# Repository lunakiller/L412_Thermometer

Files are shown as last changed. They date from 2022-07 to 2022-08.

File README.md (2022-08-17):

# L412 Thermometer
Temperature and humidity station powered by STM32L412KB MCU. The goal of the project is the longest possible battery life.

## Main components
- STM32L412KBT6 MCU
- Si7021 temperature and humidity sensor
- LCD display with PCD8544 driver
- 600mAh Li-Ion battery

## Goals
- [x] Build it on the breadboard
- [x] Show temperature and humidity data on the display
- [x] Run from the battery
- [x] Design PCB
- [ ] Measure battery voltage
- [ ] Sync time through USB
- [ ] Design 3D printed case

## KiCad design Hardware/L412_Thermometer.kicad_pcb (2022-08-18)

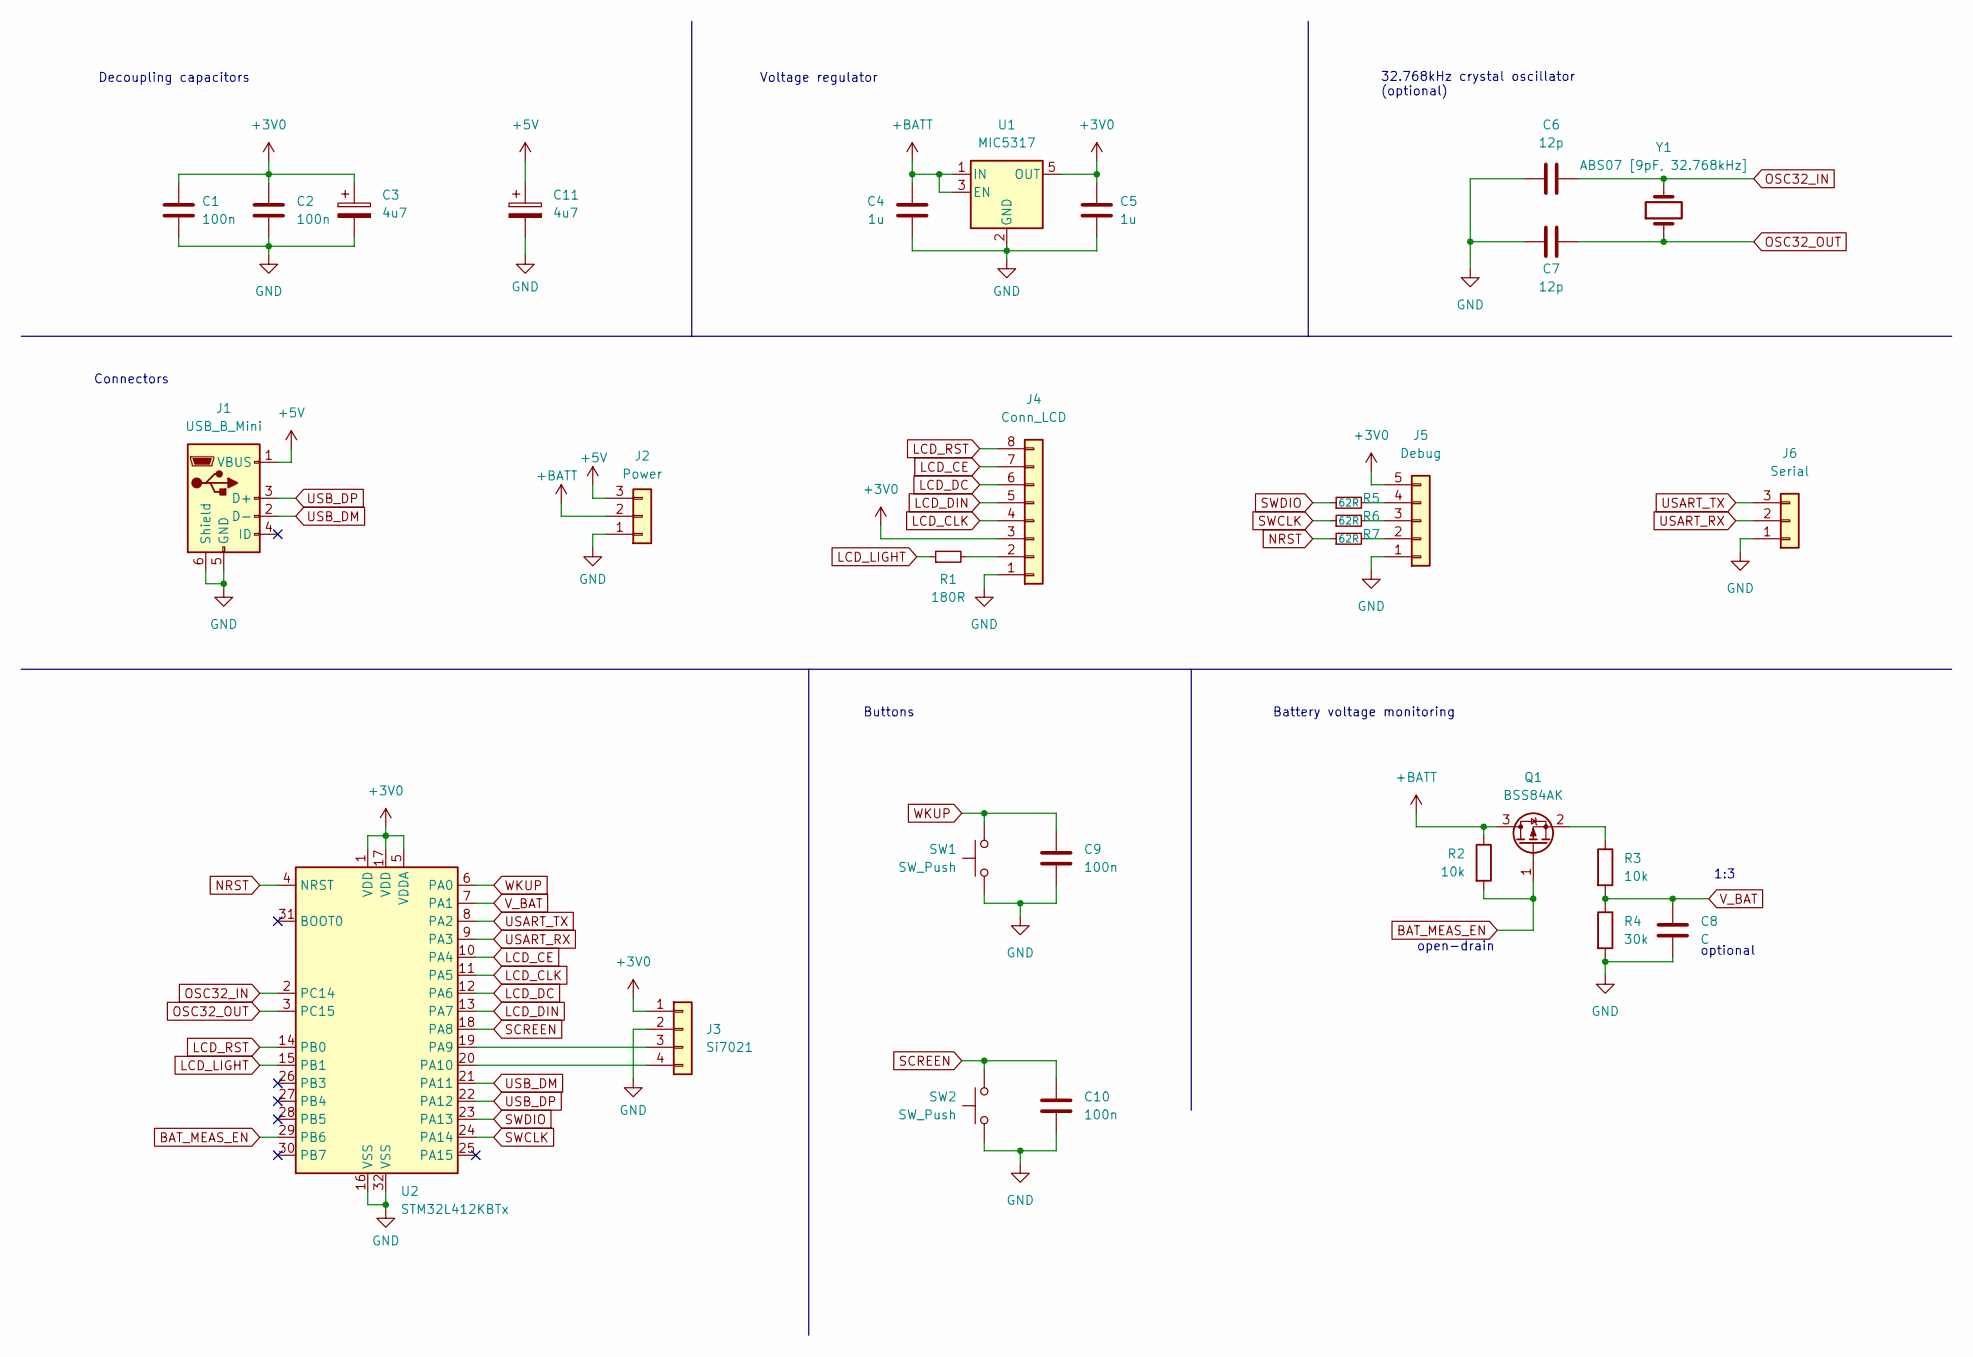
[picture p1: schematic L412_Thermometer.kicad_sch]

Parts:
C1, C2, C9, C10: 100n; C_0603_1608Metric
C3, C11: 4u7; CP_EIA-1608-10_AVX-L
C4, C5: 1u; C_0603_1608Metric
C6, C7: 12p; C_0603_1608Metric
C8: C; C_0603_1608Metric
J1: USB_B_Mini; USB_Mini-B_Lumberg_2486_01_Horizontal
J2: Power; PinHeader_1x03_P2.54mm_Vertical
J3: Si7021; PinHeader_1x04_P2.54mm_Vertical
J4: Conn_LCD; PinHeader_1x08_P2.54mm_Vertical
J5: Debug; PinHeader_1x05_P2.54mm_Vertical
J6: Serial; PinHeader_1x03_P2.54mm_Vertical
Q1: BSS84AK; SOT-23
R1: 180R; R_0603_1608Metric
R2, R3: 10k; R_0603_1608Metric
R4: 30k; R_0603_1608Metric
R5, R6, R7: 62R; R_0603_1608Metric
SW1, SW2: SW_Push; SW_SPST_SKQG_WithStem
U1: MIC5317; SOT-23-5
U2: STM32L412KBTx; LQFP-32_7x7mm_P0.8mm
Y1: ABS07 [9pF, 32.768kHz]; Crystal_SMD_3215-2Pin_3.2x1.5mm

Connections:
+3V0: C1.1, C2.1, C3.1, C5.1, J3.1, J4.3, J5.5, U1.5 (OUT), U2.1 (VDD), U2.5 (VDDA), U2.17 (VDD)
+5V: C11.1, J1.1 (VBUS), J2.3
+BATT: C4.1, J2.2, Q1.3 (D), R2.1, U1.1 (IN), U1.3 (EN)
BAT_MEAS_EN: Q1.1 (G), R2.2, U2.29 (PB6)
GND: C1.2, C2.2, C3.2, C4.2, C5.2, C6.1, C7.1, C8.2, C9.2, C10.2, C11.2, J1.5 (GND), J1.6 (Shield), J2.1, J3.2, J4.1, J5.1, J6.1, R4.2, SW1.1, SW2.1, U1.2 (GND), U2.16 (VSS), U2.32 (VSS)
LCD_CE: J4.7, U2.10 (PA4)
LCD_CLK: J4.4, U2.11 (PA5)
LCD_DC: J4.6, U2.12 (PA6)
LCD_DIN: J4.5, U2.13 (PA7)
LCD_LIGHT: R1.1, U2.15 (PB1)
LCD_RST: J4.8, U2.14 (PB0)
NRST: R7.1, U2.4 (NRST)
unnamed: J3.3, U2.19 (PA9)
unnamed: J3.4, U2.20 (PA10)
unnamed: J4.2, R1.2
unnamed: J5.2, R7.2
unnamed: J5.3, R6.2
unnamed: J5.4, R5.2
unnamed: Q1.2 (S), R3.1
OSC32_IN: C6.2, U2.2 (PC14), Y1.2
OSC32_OUT: C7.2, U2.3 (PC15), Y1.1
SCREEN: C10.1, SW2.2, U2.18 (PA8)
SWCLK: R6.1, U2.24 (PA14)
SWDIO: R5.1, U2.23 (PA13)
USART_RX: J6.2, U2.9 (PA3)
USART_TX: J6.3, U2.8 (PA2)
USB_DM: J1.2 (D-), U2.21 (PA11)
USB_DP: J1.3 (D+), U2.22 (PA12)
V_BAT: C8.1, R3.2, R4.1, U2.7 (PA1)
WKUP: C9.1, SW1.2, U2.6 (PA0)

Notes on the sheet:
1:3
Battery voltage monitoring
Buttons
open-drain
optional
32.768kHz crystal oscillator (optional)
Voltage regulator
Decoupling capacitors
Connectors

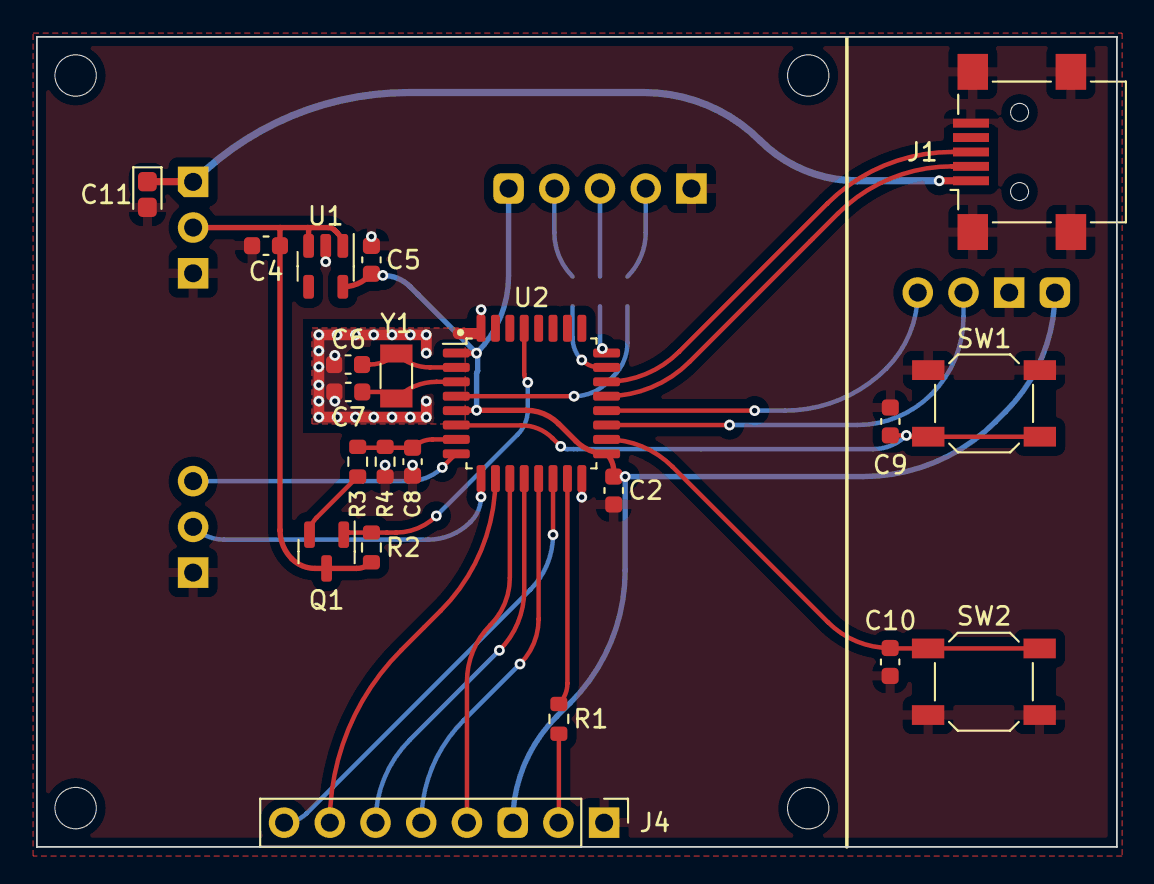
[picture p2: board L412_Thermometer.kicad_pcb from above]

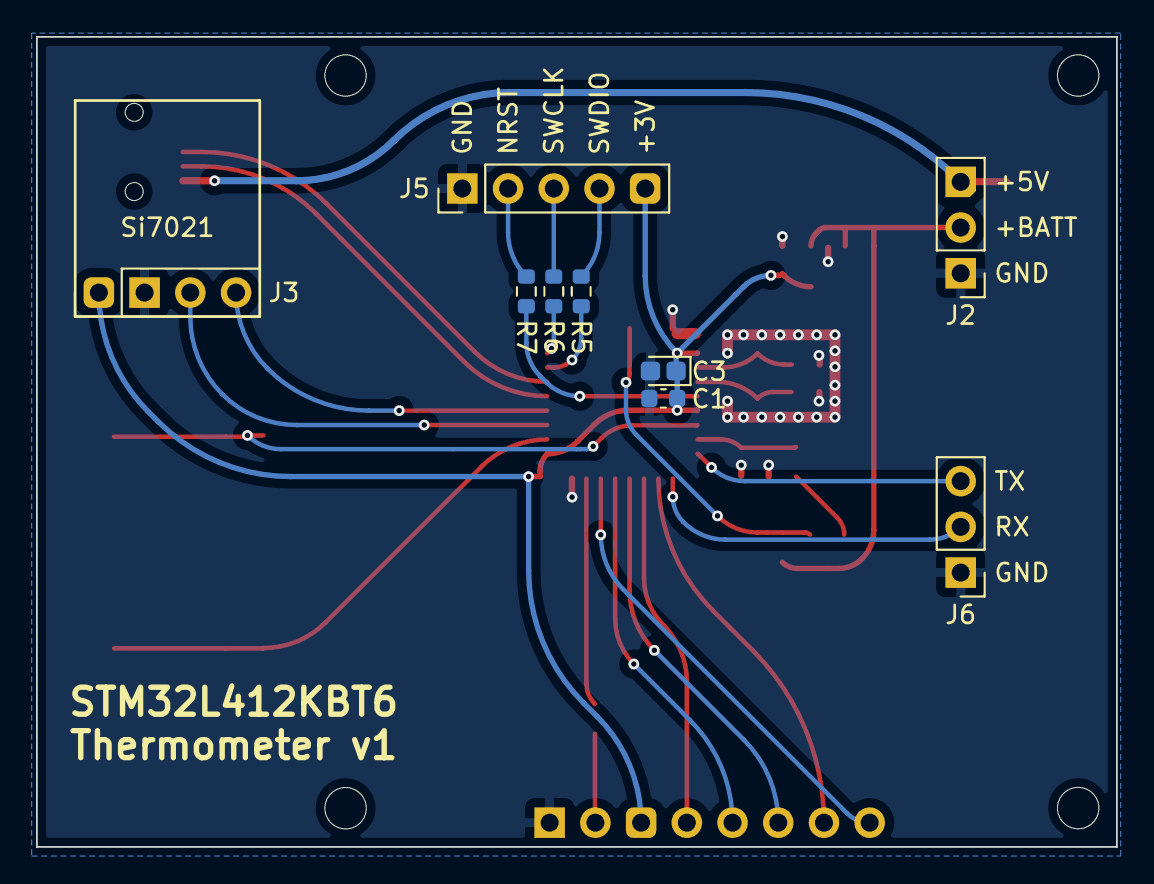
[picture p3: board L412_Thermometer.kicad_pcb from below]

Board: 2 copper layers, 60.0 x 45.0 mm, 30 parts (9 on the bottom side), 30 nets.

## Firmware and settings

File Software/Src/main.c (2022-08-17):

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
/* Includes ------------------------------------------------------------------*/
#include "main.h"
#include "usb_device.h"

/* USER CODE BEGIN Includes */
#include <stdio.h>
#include <string.h>

#include "tm_stm32f4_pcd8544.h"
#include "Si7021_driver.h"
#include "usbd_cdc_if.h"
/* USER CODE END Includes */

ADC_HandleTypeDef hadc1;

I2C_HandleTypeDef hi2c1;

UART_HandleTypeDef hlpuart1;

RTC_HandleTypeDef hrtc;

SPI_HandleTypeDef hspi1;

TIM_HandleTypeDef htim16;

/* USER CODE BEGIN PV */
TIM_HandleTypeDef Input_Handle;

uint16_t tmpCCTIM_CHANNEL_1[2] = {0, 0};
__IO uint32_t uwLsiFreq = 0;

__IO uint32_t uwCaptureNumber = 0;
__IO uint32_t uwPeriodValue = 0;
/* USER CODE END PV */

void SystemClock_Config(void);
static void MX_GPIO_Init(void);
static void MX_I2C1_Init(void);
static void MX_LPUART1_UART_Init(void);
static void MX_SPI1_Init(void);
static void MX_RTC_Init(void);
static void MX_TIM16_Init(void);
static void MX_ADC1_Init(void);
/* USER CODE BEGIN PFP */
static uint32_t GetLSIFrequency(void);
void HAL_TIM_IC_CaptureCallback(TIM_HandleTypeDef *htim);
void HAL_RTCEx_WakeUpTimerEventCallback(RTC_HandleTypeDef *hrtc);
void HAL_GPIO_EXTI_Callback(uint16_t GPIO_Pin);
/* USER CODE END PFP */

/**
  * @brief  The application entry point.
  * @retval int
  */
int main(void)
{
  /* MCU Configuration--------------------------------------------------------*/

  /* Reset of all peripherals, Initializes the Flash interface and the Systick. */
  HAL_Init();

  /* Configure the system clock */
  SystemClock_Config();

  /* Initialize all configured peripherals */
  MX_GPIO_Init();
  MX_I2C1_Init();
  MX_LPUART1_UART_Init();
  MX_SPI1_Init();
  MX_RTC_Init();
  MX_USB_DEVICE_Init();
  MX_ADC1_Init();
  /* USER CODE BEGIN 2 */
  HAL_UART_Transmit(&hlpuart1, (uint8_t*)"\n\nSTM32L412 Thermometer\r\n", 25, 1000);

  for(int i = 0; i < 5; ++i) {
    CDC_Transmit_FS((uint8_t*)"USB\r\n", 5);
    HAL_Delay(500);
  }

  MX_TIM16_Init();
  HAL_RTCEx_SetWakeUpTimer_IT(&hrtc, 59, RTC_WAKEUPCLOCK_CK_SPRE_16BITS, 0x0);

  HAL_UART_Transmit(&hlpuart1, (uint8_t*)"USB deinit..\r\n", 14, 1000);
  MX_USB_DEVICE_DeInit();
  HAL_UART_Transmit(&hlpuart1, (uint8_t*)"MSI to 4MHz..\r\n", 15, 1000);
  
  RCC_OscInitTypeDef MSI_InitStruct = {0};
  /** Initializes the RCC Oscillators according to the specified parameters
  * in the RCC_OscInitTypeDef structure.
  */
  MSI_InitStruct.OscillatorType = RCC_OSCILLATORTYPE_MSI;
  MSI_InitStruct.MSIState = RCC_MSI_ON;
  MSI_InitStruct.MSICalibrationValue = 0;
  MSI_InitStruct.MSIClockRange = RCC_MSIRANGE_6;
  if (HAL_RCC_OscConfig(&MSI_InitStruct) != HAL_OK)
  {
    Error_Handler();
  }

  RCC_ClkInitTypeDef RCC_ClkInitStruct = {0};
  /** Initializes the CPU, AHB and APB buses clocks
  */
  RCC_ClkInitStruct.ClockType = RCC_CLOCKTYPE_HCLK|RCC_CLOCKTYPE_SYSCLK
                              |RCC_CLOCKTYPE_PCLK1|RCC_CLOCKTYPE_PCLK2;
  RCC_ClkInitStruct.SYSCLKSource = RCC_SYSCLKSOURCE_MSI;
  RCC_ClkInitStruct.AHBCLKDivider = RCC_SYSCLK_DIV1;
  RCC_ClkInitStruct.APB1CLKDivider = RCC_HCLK_DIV1;
  RCC_ClkInitStruct.APB2CLKDivider = RCC_HCLK_DIV1;

  if (HAL_RCC_ClockConfig(&RCC_ClkInitStruct, FLASH_LATENCY_0) != HAL_OK)
  {
    Error_Handler();
  }

  HAL_Delay(100);
  // restart UART
  MX_LPUART1_UART_Init();
  HAL_UART_Transmit(&hlpuart1, (uint8_t*)"Done!\r\n", 7, 1000);


  /* Get the LSI frequency:  TIM16 is used to measure the LSI frequency */
  uwLsiFreq = GetLSIFrequency();
  /* Update the Calendar Configuration with the LSI exact value */
  hrtc.Instance = RTC;
  hrtc.Init.HourFormat = RTC_HOURFORMAT_24;
  hrtc.Init.AsynchPrediv = 127;
  hrtc.Init.SynchPrediv = (uwLsiFreq/128) - 1;
  hrtc.Init.OutPut = RTC_OUTPUT_DISABLE;
  hrtc.Init.OutPutRemap = RTC_OUTPUT_REMAP_NONE;
  hrtc.Init.OutPutPolarity = RTC_OUTPUT_POLARITY_HIGH;
  hrtc.Init.OutPutType = RTC_OUTPUT_TYPE_OPENDRAIN;
  hrtc.Init.OutPutPullUp = RTC_OUTPUT_PULLUP_NONE;
  if (HAL_RTC_Init(&hrtc) != HAL_OK)
  {
    Error_Handler();
  }

  HAL_TIM_IC_DeInit(&htim16);
  HAL_TIM_Base_DeInit(&htim16);


  PCD8544_Init(&hspi1, 0x38);
  //Go to x=14, y=3 position
  PCD8544_GotoXY(14, 3);
  //Print data with Pixel Set mode and Fontsize of 5x7px
  PCD8544_Puts("STM32L412", PCD8544_Pixel_Set, PCD8544_FontSize_5x7);
  //Display data on LCD
  PCD8544_Refresh();
  HAL_Delay(100);

  uint8_t revision = r_firmware_rev_Si7021();
  Si7021_resolution_t resolution = r_resolution_Si7021();
  float temp = 0, hum = 0;
  r_both_Si7021(&hum, &temp);

  uint8_t msg[64], temp_str[16], hum_str[16], iter_str[6];
  memset(msg, 0, sizeof(msg));
  sprintf((char*)msg, "Rev: %d, Res: %d; Temp: %d.%02d, Humid: %d.%02d\r\n", revision,\
    resolution, (int)temp, (int)((temp-(int)temp)*100), (int)hum, (int)((hum-(int)hum)*100));
  HAL_UART_Transmit(&hlpuart1, msg, sizeof(msg), HAL_MAX_DELAY);

  PCD8544_Clear();


  /* USER CODE END 2 */

  /* Infinite loop */
  /* USER CODE BEGIN WHILE */
  while (1)
  {
    r_both_Si7021(&hum, &temp);
    sprintf((char*)temp_str, "Temp: %d.%02d C", (int)temp, (int)((temp-(int)temp)*100));
    sprintf((char*)hum_str, "Humid: %d.%02d%%", (int)hum, (int)((hum-(int)hum)*100));
    // sprintf((char*)iter_str, "%d", iter);
    PCD8544_ClearRAM();
    PCD8544_GotoXY(3, 10);
    PCD8544_Puts((char*)temp_str, PCD8544_Pixel_Set, PCD8544_FontSize_5x7);
    PCD8544_GotoXY(3, 20);
    PCD8544_Puts((char*)hum_str, PCD8544_Pixel_Set, PCD8544_FontSize_5x7);
    // LCD_PCD8544_write_str(&gLcdScreen, 5, 9, (char*)iter_str);
    PCD8544_UpdateArea(0, 10, PCD8544_WIDTH - 1, 28);
    PCD8544_Refresh();

    if(HAL_GPIO_ReadPin(WKUP_GPIO_Port, WKUP_Pin) != GPIO_PIN_RESET) {
      HAL_UART_Transmit(&hlpuart1, (uint8_t*)"Sleep\r\n", 7, HAL_MAX_DELAY);
      HAL_SuspendTick();
      HAL_PWR_EnterSLEEPMode(PWR_MAINREGULATOR_ON, PWR_SLEEPENTRY_WFI);
    }
    else {
      HAL_UART_Transmit(&hlpuart1, (uint8_t*)"DEBUG\r\n", 7, HAL_MAX_DELAY);
      HAL_Delay(1000);
    }
    
    /* USER CODE END WHILE */

    /* USER CODE BEGIN 3 */
  }
  /* USER CODE END 3 */
}

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
/* USER CODE BEGIN 4 */
void HAL_GPIO_EXTI_Callback(uint16_t GPIO_Pin) {
  HAL_ResumeTick();
}

void HAL_RTCEx_WakeUpTimerEventCallback(RTC_HandleTypeDef *hrtc)
{    
  HAL_ResumeTick();
  HAL_UART_Transmit(&hlpuart1, (uint8_t*)"WKUP\r\n", 6, 500);
}
/**
  * @brief  Input Capture callback in non blocking mode 
  * @param  htim : TIM IC handle
  * @retval None
*/
void HAL_TIM_IC_CaptureCallback(TIM_HandleTypeDef *htim)
{
  /* Get the Input Capture value */
  tmpCCTIM_CHANNEL_1[uwCaptureNumber++] = HAL_TIM_ReadCapturedValue(&Input_Handle, TIM_CHANNEL_1);
  
  if (uwCaptureNumber >= 2)
  {
    if ( tmpCCTIM_CHANNEL_1[0] > tmpCCTIM_CHANNEL_1[1] )
    {
      /* Compute the period length */
      uwPeriodValue = (uint16_t)(0xFFFF - tmpCCTIM_CHANNEL_1[0] + tmpCCTIM_CHANNEL_1[1] + 1);
    }
    else
    {
      /* Compute the period length */
      uwPeriodValue = (uint16_t)(tmpCCTIM_CHANNEL_1[1] - tmpCCTIM_CHANNEL_1[0]);
    }
    /* Frequency computation */ 
    uwLsiFreq = (uint32_t) SystemCoreClock / uwPeriodValue;
    uwLsiFreq *= 8;
  }
}

/**
  * @brief  Configures TIM16 to measure the LSI oscillator frequency. 
  * @param  None
  * @retval LSI Frequency
  */
static uint32_t GetLSIFrequency(void)
{
  TIM_IC_InitTypeDef    TIMInput_Config;

  /* Configure the TIM peripheral *********************************************/ 
  /* Set TIMx instance */  
  Input_Handle.Instance = TIM16;
  
  /* TIM16 configuration: Input Capture mode ---------------------
     The LSI oscillator is connected to TIM16 TIM_CHANNEL_1.
     The Rising edge is used as active edge.
     The TIM16 Capture/Compare register associated to TIM_CHANNEL_1 
     is used to compute the frequency value. 
  ------------------------------------------------------------ */
  Input_Handle.Init.Prescaler         = 0; 
  Input_Handle.Init.CounterMode       = TIM_COUNTERMODE_UP;  
  Input_Handle.Init.Period            = 0xFFFF; 
  Input_Handle.Init.ClockDivision     = 0;     
  if(HAL_TIM_IC_Init(&Input_Handle) != HAL_OK)
  {
    /* Initialization Error */
    Error_Handler();
  }
  
  /* Connect internally the TIM16 Input Capture of TIM_CHANNEL_1 to the LSI clock output */
  HAL_TIMEx_RemapConfig(&Input_Handle, TIM_TIM16_TI1_LSI);
  
  /* Configure the Input Capture of TIM_CHANNEL_1 */
  TIMInput_Config.ICPolarity  = TIM_ICPOLARITY_RISING;
  TIMInput_Config.ICSelection = TIM_ICSELECTION_DIRECTTI;
  TIMInput_Config.ICPrescaler = TIM_ICPSC_DIV8;
  TIMInput_Config.ICFilter    = 0;
  if(HAL_TIM_IC_ConfigChannel(&Input_Handle, &TIMInput_Config, TIM_CHANNEL_1) != HAL_OK)
  {
    /* Initialization Error */
    Error_Handler();
  }

  /* Start the TIM Input Capture measurement in interrupt mode */
  if(HAL_TIM_IC_Start_IT(&Input_Handle, TIM_CHANNEL_1) != HAL_OK)
  {
    Error_Handler();
  }

  /* Wait until the TIM16 gets 2 LSI edges */
  while(uwCaptureNumber != 2)
  {
  }

  /* Disable TIM16 Capture/Compare channel Interrupt Request */
  HAL_TIM_IC_Stop_IT(&Input_Handle, TIM_CHANNEL_1);
  
  /* Deinitialize the TIM16 peripheral registers to their default reset values */
  HAL_TIM_IC_DeInit(&Input_Handle);

  return uwLsiFreq;
}
/* USER CODE END 4 */
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


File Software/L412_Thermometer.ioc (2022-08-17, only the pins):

Mcu.UserName=STM32L412KBTx
PA0-CK_IN.GPIO_Label=WKUP
PA0-CK_IN.Signal=GPXTI0
PA1.GPIO_Label=V_BAT
PA1.Signal=ADCx_IN6
PA10.GPIO_Label=SI7021_SDA
PA10.Signal=I2C1_SDA
PA11.Signal=USB_DM
PA12.Signal=USB_DP
PA2.Signal=LPUART1_TX
PA3.Signal=LPUART1_RX
PA4.GPIO_Label=LCD_CE
PA4.Signal=GPIO_Output
PA5.GPIO_Label=LCD_CLK
PA5.Signal=SPI1_SCK
PA6.GPIO_Label=LCD_DC
PA6.Signal=GPIO_Output
PA7.GPIO_Label=LCD_DIN
PA7.Signal=SPI1_MOSI
PA8.GPIO_Label=SCREEN
PA8.Signal=GPXTI8
PA9.GPIO_Label=SI7021_CSL
PA9.Signal=I2C1_SCL
PB0.GPIO_Label=LCD_RST
PB0.Signal=GPIO_Output
PB1.GPIO_Label=LCD_LIGHT
PB1.Signal=GPIO_Output
PB6.GPIO_Label=BAT_MEAS_EN
PB6.Signal=GPIO_Output

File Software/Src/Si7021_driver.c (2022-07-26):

#include <Si7021_driver.h>
#include "stm32l4xx_hal.h"

extern I2C_HandleTypeDef hi2c1;

static const uint16_t I2C_ADDR = (0x40<<1);           // Si7021 I2C address
static const uint8_t  HEATER_CURRENT_OFFSET = 3;      // current value in mA for register value 0
static const uint8_t  HEATER_CURRENT_STEP   = 6;      // mA/LSB

static uint8_t user_register_1 = 0b00111010;
static uint8_t heater_control_register = 0b00000000;

static float process_temp_code(uint16_t temp_code);
static float process_humi_code(uint16_t humi_code);
static uint16_t convert_to_uint16(uint8_t bytes[]);
static int8_t w_reg(uint8_t value, Si7021_registers_t reg);
static int8_t r_reg(Si7021_registers_t reg);

static float process_temp_code(uint16_t temp_code)
{
  return (float)(((175.72 * temp_code) / 65536.0) - 46.85);
}

static float process_humi_code(uint16_t humi_code)
{
  float value = (float)(((125.0 * humi_code) / 65536.0) - 6.0);

  if(value < 0)
    return 0;
  else if(value > 100)
    return 100;
  else
    return (float)value;
}

static uint16_t convert_to_uint16(uint8_t bytes[])
{
  return (uint16_t)((bytes[0]<<8) | bytes[1]);
}

static int8_t r_reg(Si7021_registers_t reg)
{
  uint8_t cmd;
  uint8_t* data;

  if(reg == User_Register_1)
  {
    cmd = R_RHT_U_reg;
    data = &(user_register_1);
  }
  else if(reg == Heater_Control_Register)
  {
    cmd = R_Heater_C_reg;
    data = &(heater_control_register);
  }
  else
    return -1;

  if(HAL_OK != HAL_I2C_Mem_Read(&hi2c1, I2C_ADDR, cmd, 1, data, 1, 10000))
    return -1;
  else
    return 0;
}

static int8_t w_reg(uint8_t value, Si7021_registers_t reg)
{
  uint16_t cmd;

  if(reg == User_Register_1)
  {
    cmd = W_RHT_U_reg;
  }
  else if(reg == Heater_Control_Register)
  {
    cmd = W_Heater_C_reg;
  }
  else
    return -1;

  if(HAL_OK != HAL_I2C_Mem_Write(&hi2c1, I2C_ADDR, cmd, 1, &value, 1, 10000))
    return -1;
  else
    return 0;
}

int8_t r_single_Si7021(float* data, Si7021_measurement_type_t type)
{
  uint8_t cmd;
  uint8_t buffer[2];
  uint16_t code;

  if(type == Humidity)
    cmd = Humi_HM;
  else if(type == Temperature)
    cmd = Temp_HM;
  else
    return -1;

  if(HAL_OK != HAL_I2C_Master_Transmit(&hi2c1, I2C_ADDR, &cmd, 1, 10000))
    return -1;

  if(HAL_OK != HAL_I2C_Master_Receive(&hi2c1, I2C_ADDR, buffer, 2, 10000))
    return -1;

  code = convert_to_uint16(buffer);

  if(type == Humidity)
    *data = process_humi_code(code);
  else if(type == Temperature)
    *data = process_temp_code(code);

  return 0;
}

int8_t r_both_Si7021(float* humidity, float* temperature)
{
  uint8_t cmd = Humi_HM;
  uint8_t buffer[2];
  uint16_t code;

  if(HAL_OK != HAL_I2C_Master_Transmit(&hi2c1, I2C_ADDR, &cmd, 1, 10000))
    return -1;

  if(HAL_OK != HAL_I2C_Master_Receive(&hi2c1, I2C_ADDR, buffer, 2, 10000))
    return -1;

  code = convert_to_uint16(buffer);
  *humidity = process_humi_code(code);

  /* There is a temperature measurement with each RH measurement */
  cmd = Temp_AH;

  if(HAL_OK != HAL_I2C_Master_Transmit(&hi2c1, I2C_ADDR, &cmd, 1, 10000))
    return -1;

  if(HAL_OK != HAL_I2C_Master_Receive(&hi2c1, I2C_ADDR, buffer, 2, 10000))
    return -1;

  code = convert_to_uint16(buffer);
  *temperature = process_temp_code(code);

  return 0;
}

int8_t r_firmware_rev_Si7021()
{
  uint16_t cmd = (R_Firm_rev2<<8) | R_Firm_rev1;
  uint8_t data;

  if(HAL_OK != HAL_I2C_Master_Transmit(&hi2c1, I2C_ADDR, (uint8_t*)(&cmd), 2, 10000))
    return -1;

  if(HAL_OK != HAL_I2C_Master_Receive(&hi2c1, I2C_ADDR, &data, 1, 10000))
    return -1;

  switch(data)
  {
    case 0xFF: return 1;
    case 0x20: return 2;
    default: return -1;
  }
}

int8_t set_resolution_Si7021(Si7021_resolution_t resolution)
{
  int8_t rv;
  uint8_t temp = user_register_1;

  switch(resolution)
  {
    case H12_T14:
    {
      user_register_1 &= (uint8_t)(~(1<<RES1) & ~(1<<RES0));
      rv = w_reg(user_register_1, User_Register_1);
      break;
    }
    case H8_T12:
    {
      user_register_1 &= (uint8_t)(~(1<<RES1));
      user_register_1 |= (1<<RES0);
      rv = w_reg(user_register_1, User_Register_1);
      break;
    }
    case H10_T13:
    {
      user_register_1 &= ~(1<<RES0);
      user_register_1 |= (1<<RES1);
      rv = w_reg(user_register_1, User_Register_1);
      break;
    }
    case H11_T11:
    {
      user_register_1 |= (1<<RES1) | (1<<RES0);
      rv = w_reg(user_register_1, User_Register_1);
      break;
    }
    default: return -1;
  }

  /* in case of write error restore local copy of the register value */
  if(rv < 0)
    user_register_1 = temp;

  return rv;
}

Si7021_resolution_t r_resolution_Si7021()
{
  if(r_reg(User_Register_1) < 0)
    return -1;

  return (user_register_1 & ((1<<RES1) | (1<<RES0)));
}

int8_t set_heater_current_Si7021(uint8_t current)
{
  uint8_t reg_val = (current - HEATER_CURRENT_OFFSET)/HEATER_CURRENT_STEP;

  if(reg_val > 0x0F)
    reg_val = 0x0F;

  if(w_reg(reg_val, Heater_Control_Register) < 0)
    return -1;

  /* in case of write success update local copy of the register value */
  heater_control_register = reg_val;

  return 0;
}

int8_t r_heater_current_Si7021()
{
  if(r_reg(Heater_Control_Register) < 0)
    return -1;

  return ((heater_control_register & (0x0F)) * HEATER_CURRENT_STEP) + HEATER_CURRENT_OFFSET;
}

int8_t VDD_warning_Si7021()
{
  if(r_reg(User_Register_1) < 0)
    return -1;

  if(user_register_1 & (1<<VDDS))
    return 1;
  else
    return 0;
}

int8_t enable_heater_Si7021(uint8_t val)
{
  int8_t rv;
  uint8_t temp = user_register_1;

  if(val == 0)
  {
    user_register_1 &= ~(1<<HTRE);
    rv = w_reg(user_register_1, User_Register_1);
  }
  else
  {
    user_register_1 |= (1<<HTRE);
    rv = w_reg(user_register_1, User_Register_1);
  }

  /* in case of write error restore local copy of the register value */
  if(rv < 0)
    user_register_1 = temp;

  return rv;
}

int8_t rst_Si7021()
{
  uint8_t cmd = Si7021_Reset;

  if(HAL_OK != HAL_I2C_Master_Transmit(&hi2c1, I2C_ADDR, &cmd, 1, 10000))
    return -1;
  else
    return 0;
}

int8_t get_register(Si7021_registers_t reg, uint8_t* rv)
{
  if(r_reg(reg) < 0)
    return -1;

  if(reg == User_Register_1)
    *rv = user_register_1;
  else
    *rv = heater_control_register;

  return 0;
}

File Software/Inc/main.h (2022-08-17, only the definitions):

#define WKUP_Pin GPIO_PIN_0
#define WKUP_GPIO_Port GPIOA
#define WKUP_EXTI_IRQn EXTI0_IRQn
#define V_BAT_Pin GPIO_PIN_1
#define V_BAT_GPIO_Port GPIOA
#define LCD_CE_Pin GPIO_PIN_4
#define LCD_CE_GPIO_Port GPIOA
#define LCD_CLK_Pin GPIO_PIN_5
#define LCD_CLK_GPIO_Port GPIOA
#define LCD_DC_Pin GPIO_PIN_6
#define LCD_DC_GPIO_Port GPIOA
#define LCD_DIN_Pin GPIO_PIN_7
#define LCD_DIN_GPIO_Port GPIOA
#define LCD_RST_Pin GPIO_PIN_0
#define LCD_RST_GPIO_Port GPIOB
#define LCD_LIGHT_Pin GPIO_PIN_1
#define LCD_LIGHT_GPIO_Port GPIOB
#define SCREEN_Pin GPIO_PIN_8
#define SCREEN_GPIO_Port GPIOA
#define SI7021_CSL_Pin GPIO_PIN_9
#define SI7021_CSL_GPIO_Port GPIOA
#define SI7021_SDA_Pin GPIO_PIN_10
#define SI7021_SDA_GPIO_Port GPIOA
#define BAT_MEAS_EN_Pin GPIO_PIN_6
#define BAT_MEAS_EN_GPIO_Port GPIOB

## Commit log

2022-08-09 PCB updated
    [L412_Thermometer.kicad_pcb, L412_Thermometer.kicad_sch]
2022-08-17 Changed SW2 pin assignment
2022-08-17 Routed PCB
    [L412_Thermometer.kicad_pcb, L412_Thermometer.kicad_sch]
2022-08-18 Voltage divider values, changed footprint of P-MOS, picked a voltage regulator
    [L412_Thermometer.kicad_pcb, L412_Thermometer.kicad_sch]

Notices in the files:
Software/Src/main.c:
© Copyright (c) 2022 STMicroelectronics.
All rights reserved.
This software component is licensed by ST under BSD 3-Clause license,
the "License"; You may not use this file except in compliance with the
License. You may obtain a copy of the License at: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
